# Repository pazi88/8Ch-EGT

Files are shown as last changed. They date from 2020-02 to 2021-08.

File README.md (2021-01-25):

# 8-Channel EGT-board


This is repository for 8-Channel EGT board. The board is meant to be used in conjuntion with aftermarker engine control units to 
measure exhaust gas temperatures in invidual cylinders. The PCB is based on eight MAX31855 chips and STM32F103C8T6 bluepill board.
The sensors to be used with this need to be K-type EGT sensors with mini K-type thermocouple connectors.

In order to program the bluepill, you will need FTDI breakout board and the code is meant to be used in Arduino IDE. The code works
with regular STM32 core board manager for Arduino: https://github.com/stm32duino/Arduino_Core_STM32

Use these settings in Arduino IDE to compile and upload the code. Choose correct COM port for your FTDI breakout board:

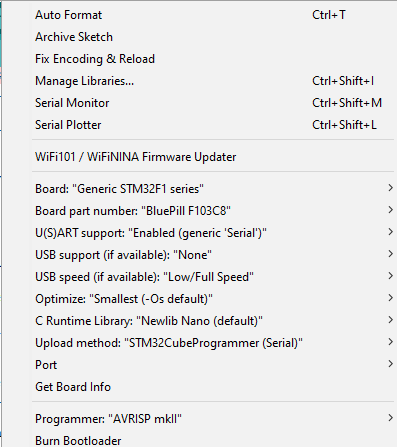
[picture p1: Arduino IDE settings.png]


The board is designed to be used in Hammond case number: 1455L1201 If you don't want silver case, with part number 1455L1201BK, you
get black case. 1455L1201BU gives blue case and 1455L1201RD red case. Link to manufacturers site: https://www.hammfg.com/part/1455L1201

EasyEda project link for the PCB: https://easyeda.com/pazi88/8ch_EGT

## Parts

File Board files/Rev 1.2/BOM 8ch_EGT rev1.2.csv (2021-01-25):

ID | Name | Designator | Footprint | Quantity | Manufacturer Part | Manufacturer | Supplier | Supplier Part | Mounted | LCSC Assembly
1 | 120 | R14 | 0603 | 1 | ? |  | LCSC | C159894
2 | 4.7k | R13 | 0603 | 1 | ? |  | LCSC | C25999
3 | B1212S-1W | U10 | B_S 1 W | 1 | B1212S-1W | Mornsun
4 | DMR-9P | DSUB1 | DMR-9P | 1 | DMR-9P | Ckmtw | LCSC | C141880
5 | 1nF | C16,C17 | C0805 | 2 | CC0805JRX7R9BB102 | YAGEO | LCSC | C277515
6 | PCC-SMP-V K-type | P1,P2,P3,P4,P5,P6,P7,P8 | PCC-SMP-V K-TYPE | 8 | PCC-SMP-V | OMEGA | Alibaba |  | No
7 | 47uF | C13,C14 | CAP-SMD_BD5.0-L5.3-W5.3-FD | 2 | RT1A470M0505 | ROQANG | LCSC | C280396
8 | Solder Jumper | JP1,JP2 | SOLDER_JUMPER_2_PADS_MEDIUM-WIDE | 2 | ?
9 | 220Ω | L1,L2,L3,L4,L5,L6,L7,L8,L9,L10,L11,L12,L13,L14,L15,L16 | L0805 | 16 | CBG201209U221T | FH | LCSC | C124102
10 | Blue Pill STM32F103C6T8 | U13 | BLUE PILL STM32F103C6T8 | 1
11 | LM2940SX-5.0/NOPB | U12 | TO-263-3 | 1 | LM2940SX-5.0/NOPB | TI | LCSC | C13980 |  | Yes
12 | 10nF | C1,C2,C3,C4,C5,C6,C7,C8 | 0805 | 8 | CL21B103KBCNNNC | SAMSUNG | LCSC | C84715 |  | Yes
13 | 10uF | C12 | CAP-SMD_BD5.0-L5.3-W5.3-FD | 1 | RVT1H100M0505 | ROQANG | LCSC | C72487
14 | 1SMA5919BT3G | D3 | SMA_L4.3-W2.6-LS5.2-RD | 1 | 1SMA5919BT3G | ON | LCSC | C20555 |  | Yes
15 | LM3940IMP-3.3/NOPB | U11 | SOT-223_L6.5-W3.5-P2.30-LS7.0-BR | 1 | LM3940IMP-3.3/NOPB | Texas Instruments | LCSC | C140319 |  | Yes
16 | 1uF | C9 | CAP-SMD_BD4.0-L4.3-W4.3-FD | 1 | MVK50VC1M4*5_4.0TP | SamYoung Electronics | LCSC | C346963
17 | 100nF | C10,C11,C15 | 1206 | 3 | GCM319R71H104KA37D | Murata Electronics | LCSC | C161270
18 | SS13 | D1 | SMA_L4.3-W2.6-LS5.2-FD | 1 | SS13 | MDD | LCSC | C64984 |  | Yes
19 | Varistor | R2 | R1206 | 1 | V18MLA1206H | Littelfuse | LCSC | C179035
20 | MCP2551T-I/SN | U9 | SOIC-8_150MIL | 1 | MCP2551T-I/SN | MICROCHIP | LCSC | C49558 |  | Yes
21 | C4201WR-F-2X3P | CN1 | C4201WR-F-2X3P | 1 | C4201WR-F-2x3P | Changjiang Connectors | LCSC | C239505
22 | MAX31855KASA+T | U1,U2,U3,U4,U5,U6,U7,U8 | SO-8_L4.9-W3.9-P1.27-LS5.9-BL | 8 | MAX31855KASA+T | MAXIM | LCSC | C52028 |  | Yes
23 | Serial | P9 | HDR-6X1/2.54 | 1 | Female header 1*6p | BOOMELE | LCSC | C40877

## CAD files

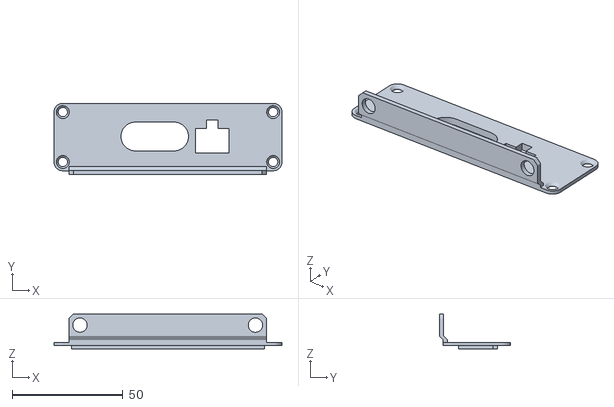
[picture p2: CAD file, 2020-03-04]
Case/End_plate1.stl
103.0 x 32.3 x 15.8

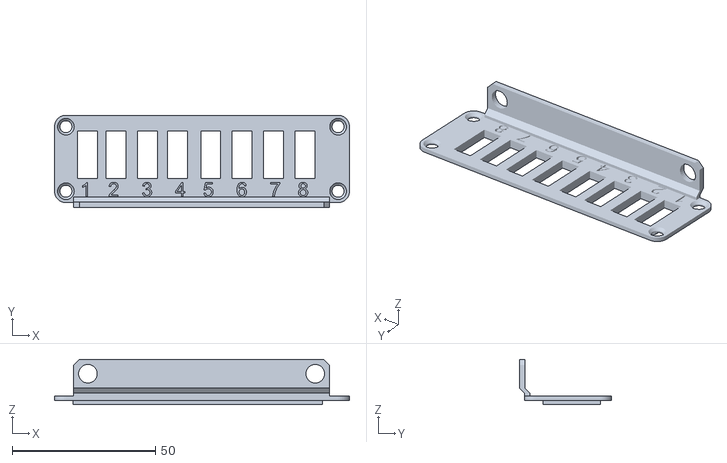
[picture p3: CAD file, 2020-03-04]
Case/End_plate2.stl
103.0 x 32.3 x 15.8

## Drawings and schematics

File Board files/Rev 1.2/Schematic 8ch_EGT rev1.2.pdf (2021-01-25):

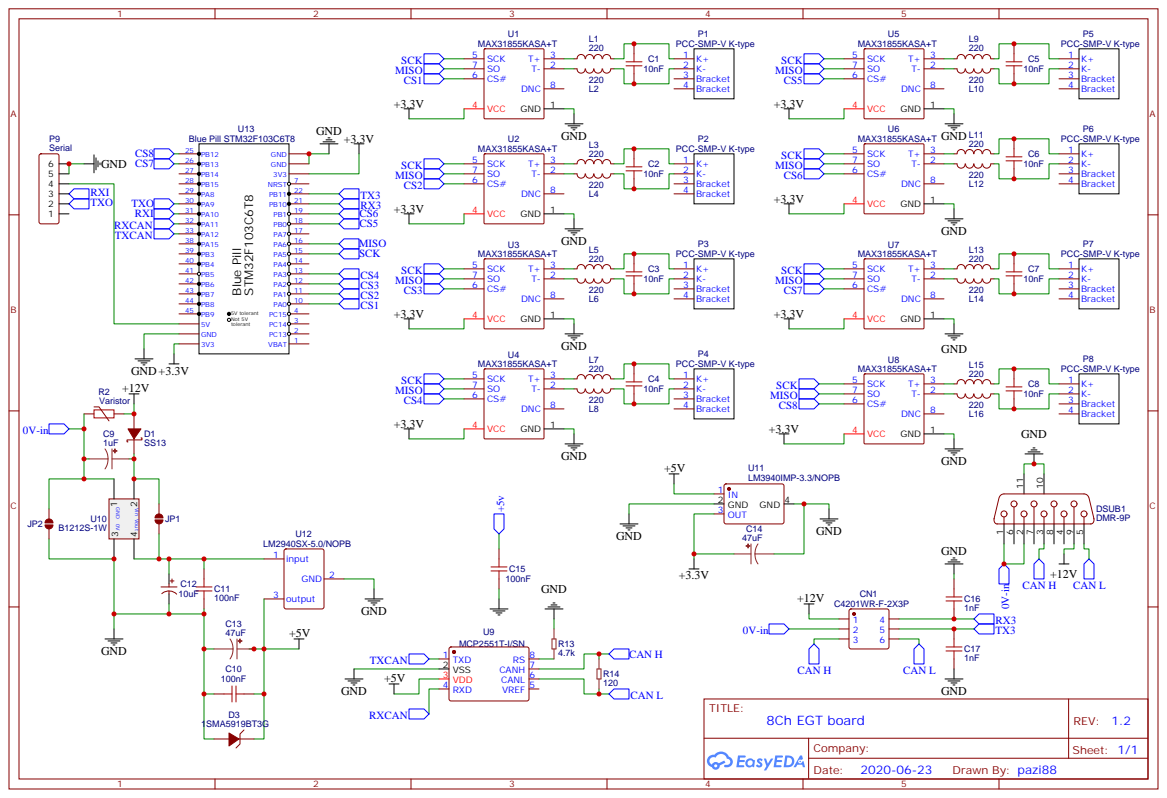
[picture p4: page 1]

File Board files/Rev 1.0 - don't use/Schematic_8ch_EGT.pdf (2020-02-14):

# U13 Blue Pill STM³²F103C6T8

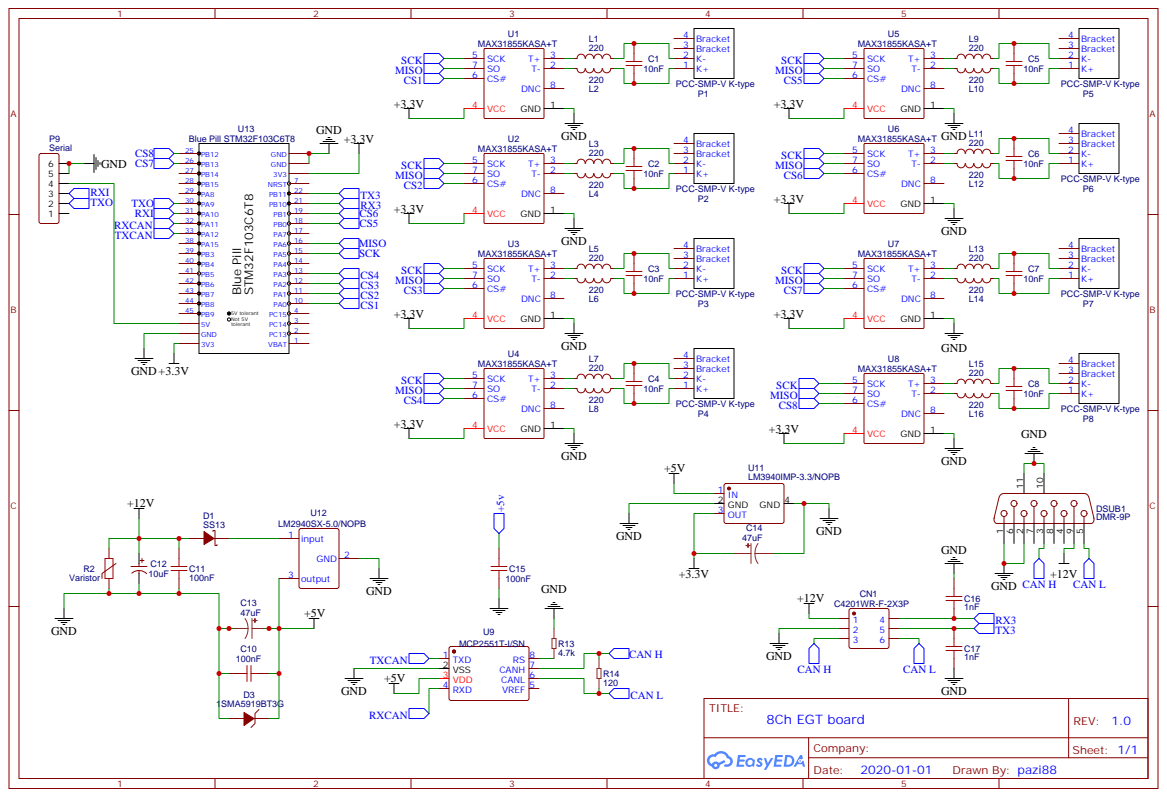
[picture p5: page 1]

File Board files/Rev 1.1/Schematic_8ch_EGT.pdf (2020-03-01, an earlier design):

# U13 Blue Pill STM³²F103C6T8

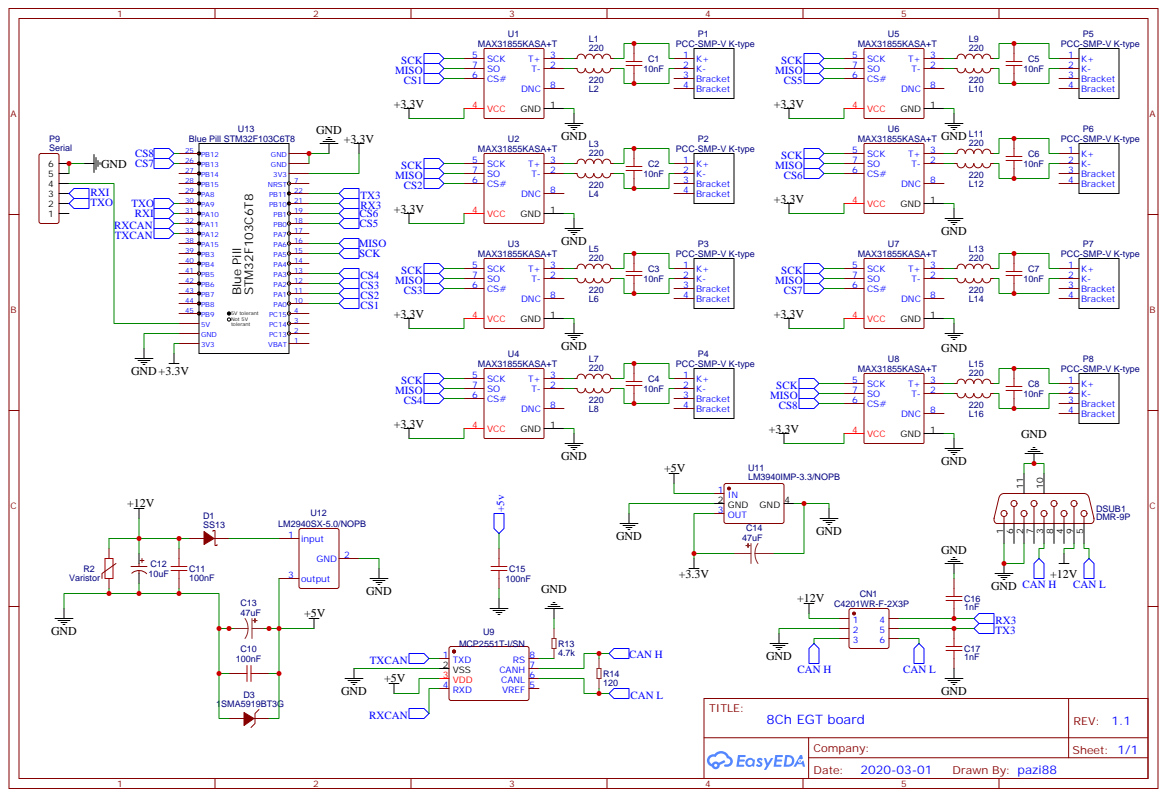
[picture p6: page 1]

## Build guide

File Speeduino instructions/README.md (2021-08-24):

# Instructions for Speeduino

To use this EGT box with speeduino, go to "Accesories" -tab and open "Canbus/Secondary Serial IO interface" -settings. There enable the Second Serial (and internal canbus if available):
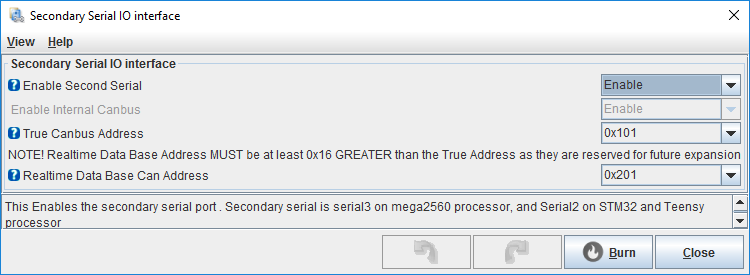
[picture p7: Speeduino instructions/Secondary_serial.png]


Then go to "External Auxilary Input Channel Configuration" -settings and use these settings to make the EGT box work:
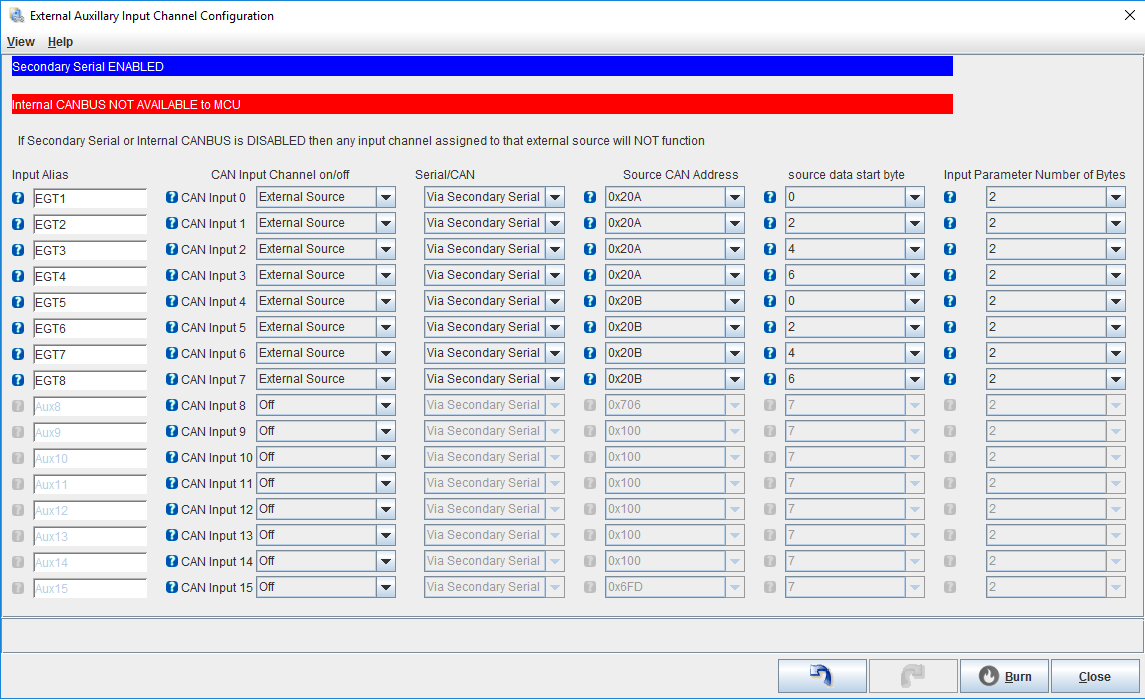
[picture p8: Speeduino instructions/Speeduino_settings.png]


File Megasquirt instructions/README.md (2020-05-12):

# Instructions for Megasquirt

To use this EGT box with megasquirt3, go to "CAN-bus/Testmodes" -tab and open "CAN receiving" -settings. These are the settings to be used:
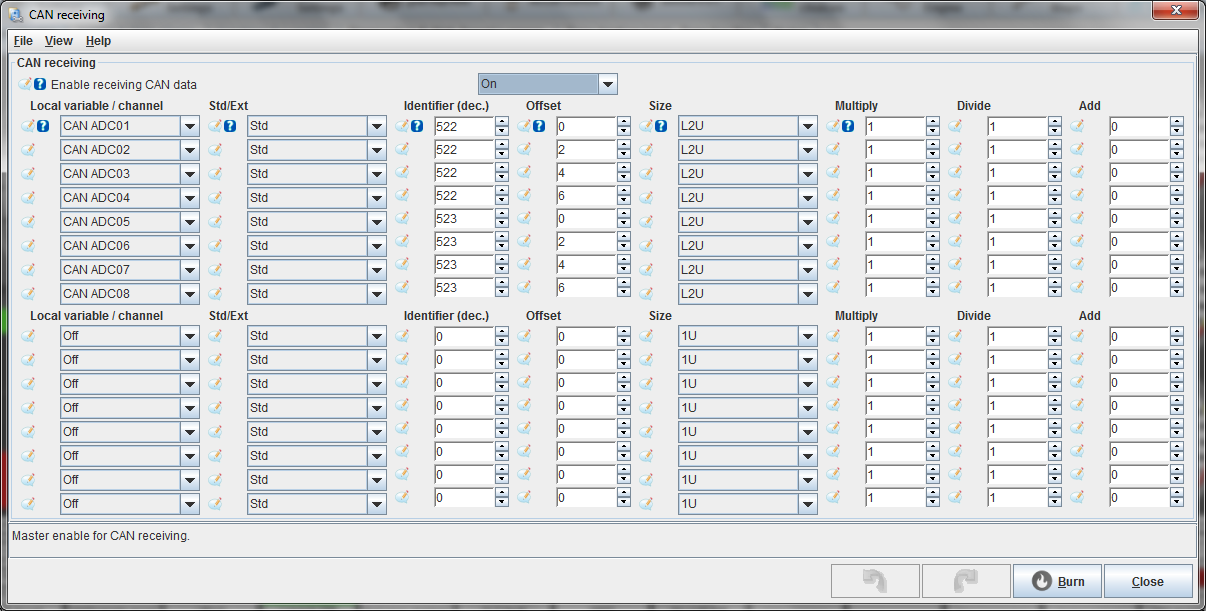
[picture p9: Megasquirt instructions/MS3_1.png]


In addition to CAN receiving settings, you need to go to "Advanced Engine" -tab and open "Generic Sensor Inputs" -settings. And use these settings there:
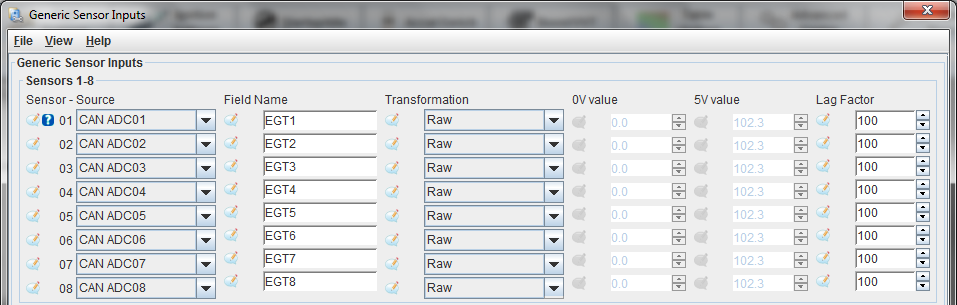
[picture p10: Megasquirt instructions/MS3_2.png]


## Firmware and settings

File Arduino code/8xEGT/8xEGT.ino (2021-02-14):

#include "MAX31855.h"
#ifdef ARDUINO_BLUEPILL_F103C8
HardwareSerial Serial3(USART3); //for some reason this isn't defined in arduino_core_stm32
#endif

#define Sensor1_4_CAN_ADDRESS   0x20A //the data from sensers 1-4 will be sent using this address
#define Sensor5_8_CAN_ADDRESS   0x20B //the data from sensers 5-8 will be sent using this address

enum BITRATE{CAN_50KBPS, CAN_100KBPS, CAN_125KBPS, CAN_250KBPS, CAN_500KBPS, CAN_1000KBPS};

typedef struct
{
  uint16_t id;
  uint8_t  data[8];
  uint8_t  len;
} CAN_msg_t;

typedef const struct
{
  uint8_t TS2;
  uint8_t TS1;
  uint8_t BRP;
} CAN_bit_timing_config_t;
CAN_bit_timing_config_t can_configs[6] = {{2, 13, 45}, {2, 15, 20}, {2, 13, 18}, {2, 13, 9}, {2, 15, 4}, {2, 15, 2}};

extern CAN_bit_timing_config_t can_configs[6];

uint8_t cs[8] = { PA0, PA1, PA2, PA3, PB0, PB1, PB13, PB12 }; //chip select pins for the MAX31855 chips
int32_t rawData[8]  = { 0 }; //raw data from all 8 MAX31855 chips
float EGT[8]  = { 0 }; //calculated EGT values from all 8 MAX31855 chips
float ColdJunction[8]  = { 0 }; //calculated cold junction temperatures from all 8 MAX31855 chips, not needed for any other than debugging
CAN_msg_t CAN_msg_14;    // data from EGT 1-4 that will be sent to CAN bus
CAN_msg_t CAN_msg_58;    // data from EGT 5-8 that will be sent to CAN bus
uint16_t CanAddress;
byte canin_channel;
byte MAX31855_OK_bits; // this is used to check if all MAX31855 chips are working or even installed and code skips the ones that don't work.

MAX31855 MAX31855_chips[8] = {
  MAX31855(cs[0]),
  MAX31855(cs[1]),
  MAX31855(cs[2]),
  MAX31855(cs[3]),
  MAX31855(cs[4]),
  MAX31855(cs[5]),
  MAX31855(cs[6]),
  MAX31855(cs[7])
};

void CANInit(enum BITRATE bitrate)
 {
    RCC->APB1ENR |= 0x2000000UL;      // Enable CAN clock 
    RCC->APB2ENR |= 0x1UL;            // Enable AFIO clock

    AFIO->MAPR   &= 0xFFFF9FFF;       // reset CAN remap
    AFIO->MAPR   |= 0x00000000;       //  et CAN remap, use PA11, PA12
 
    RCC->APB2ENR |= 0x4UL;            // Enable GPIOA clock (bit2 to 1)
    GPIOA->CRH   &= 0xFFF00FFF;
    GPIOA->CRH   |= 0xB8000UL;            // Configure PA11 and PA12
    GPIOA->ODR   |= 0x1000UL;
  
    CAN1->MCR = 0x51UL;                // Set CAN to initialization mode
     
    // Set bit rates 
    CAN1->BTR &= ~(((0x03) << 24) | ((0x07) << 20) | ((0x0F) << 16) | (0x1FF)); 
    CAN1->BTR |=  (((can_configs[bitrate].TS2-1) & 0x07) << 20) | (((can_configs[bitrate].TS1-1) & 0x0F) << 16) | ((can_configs[bitrate].BRP-1) & 0x1FF);
 
// Configure Filters to default values
    CAN1->FMR  |=   0x1UL;                // Set to filter initialization mode
    CAN1->FMR  &= 0xFFFFC0FF;             // Clear CAN2 start bank
    CAN1->FMR  |= 0x1C << 8;              // Assign all filters to CAN1
    CAN1->FA1R &= ~(0x1UL);               // Deactivate filter 0
    CAN1->FS1R |=   0x1UL;                // Set first filter to single 32 bit configuration

 
    CAN1->sFilterRegister[0].FR1 = 0x0UL; // Set filter registers to 0
    CAN1->sFilterRegister[0].FR2 = 0x0UL; // Set filter registers to 0
    CAN1->FM1R &= ~(0x1UL);               // Set filter to mask mode
 
    CAN1->FFA1R &= ~(0x1UL);              // Apply filter to FIFO 0  
    CAN1->FA1R  |=   0x1UL;               // Activate filter 0
    
    CAN1->FMR   &= ~(0x1UL);              // Deactivate initialization mode
    CAN1->MCR   &= ~(0x1UL);              // Set CAN to normal mode 

    while (CAN1->MSR & 0x1UL); 
 
 }

void setup() {
  pinMode(LED_BUILTIN, OUTPUT);
  MAX31855_OK_bits = 0;
  Serial.begin(115200); //debug
  Serial3.begin(115200); //data to speeduino
  CANInit(CAN_500KBPS); //init can at 500KBPS speed
  CAN_msg_14.len = 8; //8 bytes in can message
  CAN_msg_58.len = 8;
  CAN_msg_14.id = Sensor1_4_CAN_ADDRESS;
  CAN_msg_58.id = Sensor5_8_CAN_ADDRESS;

// begin communication to MAX31855 chips
  for (int i=0; i<8; i++) {
    MAX31855_chips[i].begin();
  }

// check that all MAX31855 chips work or are even installed
  for (int i=0; i<8; i++) {
    if (MAX31855_chips[i].readRawData() != 0){  //we will just get 0 if there is no chip at all.
      if (MAX31855_chips[i].getChipID() != MAX31855_ID) //if there is something there, check that it responds like MAX31855 (maybe useless step)
      {
        Serial.print("MAX31855 ");
        Serial.print(i+1);
        Serial.println(" Error");
      }
      else{
        Serial.print("MAX31855 ");
        Serial.print(i+1);
        Serial.println(" Ok");
        bitSet(MAX31855_OK_bits, i); //set corresponding bit to 1
      }
    }
    else{
      Serial.print("Can't find MAX31855 "); //nothing in this CS line
      Serial.println(i+1);
    }
  }
}

void CheckDataRequest(){
  if (Serial3.read() == 'R'){
     byte tmp0;
     byte tmp1;
     if ( Serial3.available() >= 3)
     {
      canin_channel = Serial3.read();
      tmp0 = Serial3.read();  //read in lsb of source can address 
      tmp1 = Serial3.read();  //read in msb of source can address
      CanAddress = tmp1<<8 | tmp0 ;
      if (CanAddress == Sensor1_4_CAN_ADDRESS || CanAddress == Sensor5_8_CAN_ADDRESS){  //check if the speeduino request includes adresses for EGTs
        SendDataToSpeeduino();  //request ok, send the data to speeduino
      }
     }
  }
}

void SendDataToSpeeduino(){
  Serial3.write("G");                      // reply "G" cmd
  Serial3.write(1);                        //send 1 to confirm cmd received and valid
  Serial3.write(canin_channel);            //confirms the destination channel
  if (CanAddress == Sensor1_4_CAN_ADDRESS){
    for (int i=0; i<8; i++) {
        Serial3.write(CAN_msg_14.data[i]);
    }
  }
  if (CanAddress == Sensor5_8_CAN_ADDRESS){
    for (int i=0; i<8; i++) {
        Serial3.write(CAN_msg_58.data[i]);
    }
  }
}

void CANSend(CAN_msg_t* CAN_tx_msg)
 {
    volatile int count = 0;
     
    CAN1->sTxMailBox[0].TIR   = (CAN_tx_msg->id) << 21;
    
    CAN1->sTxMailBox[0].TDTR &= ~(0xF);
    CAN1->sTxMailBox[0].TDTR |= CAN_tx_msg->len & 0xFUL;
    
    CAN1->sTxMailBox[0].TDLR  = (((uint32_t) CAN_tx_msg->data[3] << 24) |
                                 ((uint32_t) CAN_tx_msg->data[2] << 16) |
                                 ((uint32_t) CAN_tx_msg->data[1] <<  8) |
                                 ((uint32_t) CAN_tx_msg->data[0]      ));
    CAN1->sTxMailBox[0].TDHR  = (((uint32_t) CAN_tx_msg->data[7] << 24) |
                                 ((uint32_t) CAN_tx_msg->data[6] << 16) |
                                 ((uint32_t) CAN_tx_msg->data[5] <<  8) |
                                 ((uint32_t) CAN_tx_msg->data[4]      ));

    CAN1->sTxMailBox[0].TIR  |= 0x1UL;
    while(CAN1->sTxMailBox[0].TIR & 0x1UL && count++ < 1000000);
     
     if (!(CAN1->sTxMailBox[0].TIR & 0x1UL)) return;
     
     //Sends error log to screen
     while (CAN1->sTxMailBox[0].TIR & 0x1UL)
     {
         Serial.println(CAN1->ESR);        
         Serial.println(CAN1->MSR);        
         Serial.println(CAN1->TSR);
        
     }
 }

void loop() {
   for (int i=0; i<8; i++) {
    if (bitRead(MAX31855_OK_bits, i) == 1){
     rawData[i] = MAX31855_chips[i].readRawData();
     Serial.print("EGT");
     Serial.print(i+1);
     switch (MAX31855_chips[i].detectThermocouple(rawData[i]))
     {
       case MAX31855_THERMOCOUPLE_OK:
         EGT[i]  = (MAX31855_chips[i].getTemperature(rawData[i]));
         Serial.print(" Temp: ");
         Serial.println(EGT[i]);
         break;
       case MAX31855_THERMOCOUPLE_SHORT_TO_VCC:
         Serial.println(" SHORT TO VCC");
         EGT[i]  = 2000;
         break;
       case MAX31855_THERMOCOUPLE_SHORT_TO_GND:
         Serial.println(" SHORT TO GND");
         EGT[i]  = 3000;
         break;
       case MAX31855_THERMOCOUPLE_NOT_CONNECTED:
         Serial.println(" NOT CONNECTED");
         EGT[i]  = 4000;
         break;
       default:
         Serial.println(" MAX31855 ERROR");
         EGT[i]  = 5000;
         break;
     }
     ColdJunction[i]  = (MAX31855_chips[i].getColdJunctionTemperature(rawData[i]));
     if (i < 4){
      CAN_msg_14.data[2*i] = lowByte(uint16_t(EGT[i]));
      CAN_msg_14.data[2*i+1] = highByte(uint16_t(EGT[i]));
     }
     else{
      CAN_msg_58.data[2*i-8] = lowByte(uint16_t(EGT[i]));
      CAN_msg_58.data[2*i-7] = highByte(uint16_t(EGT[i]));
     }
      while (Serial3.available () > 0) {  //is there data on serial3, presumably from speeduino
        CheckDataRequest(); //there is data, but is request from speeduino and is it for EGTs
      }
        if (i < 4){
         CANSend(&CAN_msg_14);
       }
       else{
         CANSend(&CAN_msg_58);
       }
     Serial.print("Cold Junction");
     Serial.print(i+1);
     Serial.print(" Temp: ");
     Serial.println(ColdJunction[i]);
     if (i == 1){ digitalWrite(LED_BUILTIN, !digitalRead(LED_BUILTIN)); } // Just flash bluilt in led in bluepill to see that the whole thing is working
    }
  }
}

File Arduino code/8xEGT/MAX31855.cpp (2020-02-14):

/***************************************************************************************************/
/*
   This is an Arduino library for 14-bit MAX31855 K-Thermocouple to Digital Converter
   with 12-bit Cold Junction Compensation conneted to hardware 5Mhz SPI with maximum sampling
   rate ~9..10Hz.

   - MAX31855 maximum power supply voltage is 3.6v
   - K-type thermocouples have an absolute accuracy of around ±2°C..±6°C.
   - Measurement tempereture range -200°C..+700°C ±2°C or -270°C..+1372°C ±6°C
     with 0.25°C resolution/increment.
   - Cold junction compensation range -40°C..+125° ±3°C with 0.062°C resolution/increment.
     Optimal performance of cold junction compensation happends when the thermocouple cold junction
     & the MAX31855 are at the same temperature. Avoid placing heat-generating devices or components
     near the converter because this may produce an errors.
   - It is strongly recommended to add a 10nF/0.01mF ceramic surface-mount capacitor, placed across
     the T+ and T- pins, to filter noise on the thermocouple lines.
     
   written by : enjoyneering79
   sourse code: https://github.com/enjoyneering/MAX31855

   This sensor uses SPI bus to communicate, specials pins are required to interface
   Board:                                    MOSI        MISO        SCLK         SS, don't use for CS   Level
   Uno, Mini, Pro, ATmega168, ATmega328..... 11          12          13           10                     5v
   Mega, Mega2560, ATmega1280, ATmega2560... 51          50          52           53                     5v
   Due, SAM3X8E............................. ICSP4       ICSP1       ICSP3        x                      3.3v
   Leonardo, ProMicro, ATmega32U4........... 16          14          15           x                      5v
   Blue Pill, STM32F103xxxx boards.......... PA17        PA6         PA5          PA4                    3v
   NodeMCU 1.0, WeMos D1 Mini............... GPIO13/D7   GPIO12/D6   GPIO14/D5    GPIO15/D8*             3v/5v
   ESP32.................................... GPIO23/D23  GPIO19/D19  GPIO18/D18   x                      3v

                                             *if GPIO2/D4 or GPIO0/D3 is used for for CS, apply an external
                                              25kOhm pullup-down resistor otherwise reset & reset button
                                              may not work

   Frameworks & Libraries:
   ATtiny Core           - https://github.com/SpenceKonde/ATTinyCore
   ESP32 Core            - https://github.com/espressif/arduino-esp32
   ESP8266 Core          - https://github.com/esp8266/Arduino
   STM32 Core            - https://github.com/rogerclarkmelbourne/Arduino_STM32

   GNU GPL license, all text above must be included in any redistribution,
   see link for details  - https://www.gnu.org/licenses/licenses.html
*/
/***************************************************************************************************/

#include "MAX31855.h"


/**************************************************************************/
/*
    MAX31855()

    Constructor for hardware read only SPI

    NOTE:
     - cs is chip select, set CS low to enable the serial interface
*/
/**************************************************************************/
MAX31855::MAX31855(uint8_t cs)
{
  _cs = cs; //cs chip select
}

/**************************************************************************/
/*
    begin()

    Initializes & configures hardware SPI
*/
/**************************************************************************/
void MAX31855::begin(void)
{
  pinMode(_cs, OUTPUT);
  digitalWrite(_cs, HIGH);                  //disables SPI interface for MAX31855, but it will initiate measurement/conversion

  SPI.begin();                              //setting hardware SCK, MOSI, SS to output, pull SCK, MOSI low & SS high    

  delay(MAX31855_CONVERSION_POWER_UP_TIME);
}

/**************************************************************************/
/*
    detectThermocouple()

    Checks if thermocouple is open, shorted to GND, shorted to VCC

    Return:
    - 0 OK
    - 1 short to VCC
    - 2 short to GND
    - 3 not connected

    NOTE:
    - bit D16 is normally low & goes high if thermocouple is open, shorted to GND or VCC
    - bit D2  is normally low & goes high to indicate a hermocouple short to VCC
    - bit D1  is normally low & goes high to indicate a thermocouple short to GND
    - bit D0  is normally low & goes high to indicate a thermocouple open circuit
*/
/**************************************************************************/
uint8_t MAX31855::detectThermocouple(int32_t rawValue)
{
  if (rawValue == MAX31855_FORCE_READ_DATA) rawValue = readRawData();

  if (bitRead(rawValue, 16) == 1)
  {
    if      (bitRead(rawValue, 2) == 1) return MAX31855_THERMOCOUPLE_SHORT_TO_VCC;
    else if (bitRead(rawValue, 1) == 1) return MAX31855_THERMOCOUPLE_SHORT_TO_GND;
    else if (bitRead(rawValue, 0) == 1) return MAX31855_THERMOCOUPLE_NOT_CONNECTED;
    else                                return MAX31855_THERMOCOUPLE_UNKNOWN;
  }
  return MAX31855_THERMOCOUPLE_OK;
}

/**************************************************************************/
/*
    getChipID()

    Checks chip ID

    NOTE:
    - bit D17, D3 always return zero & can be used as device ID
*/
/**************************************************************************/
uint16_t MAX31855::getChipID(int32_t rawValue)
{
  if (rawValue == MAX31855_FORCE_READ_DATA) rawValue = readRawData();

  if (bitRead(rawValue, 17) == 0 && bitRead(rawValue, 3) == 0) return MAX31855_ID;

  return 0;
}

/**************************************************************************/
/*
    getTemperature()

    Reads Temperature, C

    NOTE:
    - range -200°C..+700°C ±2°C or -270°C..+1372°C ±6°C with 0.25°C
      resolution/increment
    - thermocouple temperature data is 14-bit long
    - bit D31 is the thermocouple temperature sign bit "+" is high & "-" is low,
      if T+ and T- are unconnected it goes low
    - bits D30..D18 contain the converted temperature in the order of MSB to LSB,
      if T+ and T- are unconnected they go high
    - it is strongly recommended to add a 10nF/0.01mF ceramic surface-mount
      capacitor, placed across the T+ and T- pins, to filter noise on the
      thermocouple lines
*/
/**************************************************************************/
float MAX31855::getTemperature(int32_t rawValue)
{
  if (rawValue == MAX31855_FORCE_READ_DATA) rawValue = readRawData();

  if (detectThermocouple(rawValue) != MAX31855_THERMOCOUPLE_OK || getChipID(rawValue) != MAX31855_ID) return MAX31855_ERROR;

  rawValue = rawValue >> 18; //clear D17..D0 bits

  return (float)rawValue * MAX31855_THERMOCOUPLE_RESOLUTION;
}
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

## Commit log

2020-02-14 BOM added
    I will later add better one
    [BOM_8ch_EGT.csv]
2020-02-14 Schematic added
    [BOM_8ch_EGT.csv]
2020-03-01 Rev 1.1 added
    Rev 1.0 had sensor wires mixed and PCB too short for case that I planned this to use. So 1.1 has now those fixed.
    [BOM_8ch_EGT.csv]
2020-03-01 Updated readme and code
    Added readme to include info about case and updated code so that it compiles with arduino_STM32_core too.
2020-03-02 Bug fix for occasional wrong values in speeduino
    [8xEGT.ino]
2020-03-02 Added filtering
2020-03-04 End plate 3D models added
    [End_plate1.stl, End_plate2.stl]
2020-03-06 Correct CAN pins to use
    [8xEGT.ino]
2020-03-16 Create Arduino IDE settings.png
2021-01-25 Add rev 1.2
    [BOM 8ch_EGT rev1.2.csv, PickAndPlace 8ch_EGT rev1.2.csv]
2021-02-14 Add fault detection and error codes
    [8xEGT.ino]
